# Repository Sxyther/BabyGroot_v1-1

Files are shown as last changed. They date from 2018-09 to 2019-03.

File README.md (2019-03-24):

# babygroot_v1-1
BabyGroot version 1.1 

---------------------------------------------------------------------------------------------------------------------
Software License: GPL v3

---------------------------------------------------------------------------------------------------------------------
Hardware License: CERN
Hardware released under an CERN Open Hardware Licence v1.2. See the LICENSE_HARDWARE file for more information.

---------------------------------------------------------------------------------------------------------------------
Documentation License: Creative Commons
Esta obra está bajo una Licencia Creative Commons Atribución-CompartirIgual 4.0 Internacional.

MakersGDL is a registered trademark, please do not use if you reproduce to sell PCBs.

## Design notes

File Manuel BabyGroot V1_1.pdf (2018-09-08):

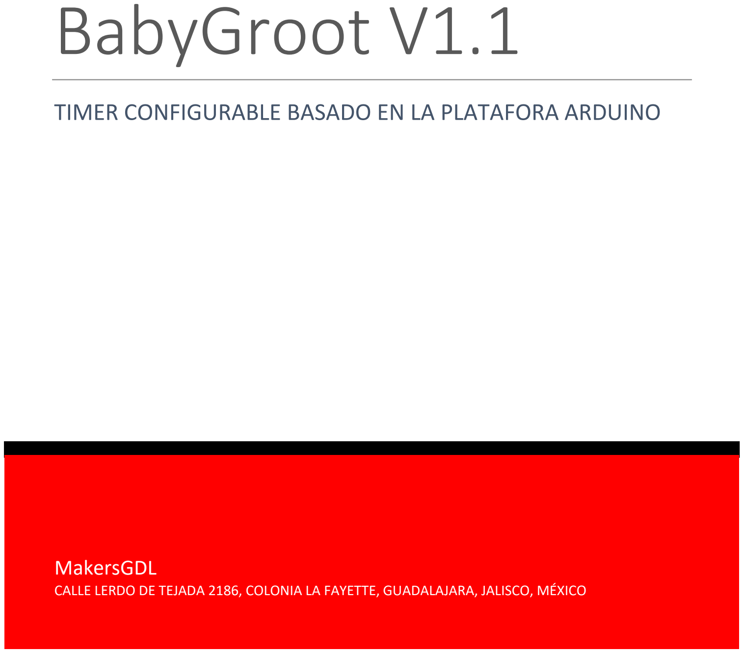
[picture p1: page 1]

[Escriba aquí] | [Escriba aquí] | [Escriba aquí]

## MakersGDL

CALLE LERDO DE TEJADA 2186, COLONIA LA FAYETTE, GUADALAJARA, JALISCO, MÉXICO

# BabyGroot V1.1

## TIMER CONFIGURABLE BASADO EN LA PLATAFORA ARDUINO

MakersGDL
www.makersgdl.com | 2

# Tabla de Contenido

### 1. INTRODUCCION A BABYGROOT V1.1

Dentro de la cultura MAKER la automatización juega un reto muy importante y desafiante. Así nace BabyGroot V1, por una necesidad de controlar valvular para el riego de un jardín a bajo costo.

### 2. DESCRIPCIÓN DE BABYGROOT V1.1

Esta guía se solo cubre BabyGroot V1.1, la tarjeta está diseñada para trabajar como un Arduino UNO vía un convertidor FTDI al puerto USB de la computadora.

Características | Detalles
Nombre | BabyGroot V1.1
Uso | Riego, invernadero, iluminación, bombas.
Canales PWM | 4
Entrada Análogos | 4
Entrada Digitales | 6
Protocolo de Comunicación | 1wire, I2C, SPI
Corriente de Entrada | 12v, 2A
Corriente de Salida | 12v
Indicador de Estatus | SI
Pantalla LCD | OPCIONAL, puede conectarse con I2C
Menú de Programación | NO, puede usarse botone de entrada
Programador en Tarjeta | NO, necesitas un TTL a USB
Software para programar | IDE Arduino
Conexión WIFI | OPCIONAL, pines disponibles
Conexión Bluetooth | OPCIONAL, pines disponibles

MakersGDL

### 3. INSTRUCCIONES DE ENSAMBLADO

Esta sección cubre el ensamblaje de la tarjeta controladora BabyGroot v1.1. Se acerca esta tarea como un ejercicio de aprendizaje, para desarrollar habilidades y autoconfianza. Este proyecto en sí es muy fácil y si sigues los pasos con cuidado, debes de terminar con un controlador funcionando completamente.

### 3.1. BabyGroot V1.1 / lista de componentes

El siguiente listado de componentes es para construir la tarjeta BabyGroot V1.1, la lista la puedes conseguir directamente con Mouser o en tu tienda de electrónica local.

Referencia | Descripción | Cantidad | Mouser P/N | Alterno P/N
D1 | 1N4004 diodo | 1
C1 | 0.1uF capacitor | 1
C2 - C3 | 22pF capacitor | 2
C4 | 4.7uF capacitor electrolítico | 1
C5 | 0.47uF capacitor electrolítico | 1
R1 - R2 | 4.7k ohm resistencia 1/8 watt | 2
R3 | 15k ohm resistencia 1/8 watt | 1
R4 - R9 | 470 ohm resistencia 1/8 watt | 6
LED1 – LED5 | 3mm led azul | 5
LED6 | 3mm led rojo | 1
OUT1-OUT5 | Borne doble | 5
PWRIN | Borne doble | 1
JP1, JP6 | 6 pines header hembra | 1
JP2, JP5 – JP8 | 3 pines header macho | 5
IC1 | Atmel 328p | 1
IC2 | ULN2003AN | 1
IC3 | 7805TV | 1
1 | Botón | 1
Q1 | Cristal 16mhz | 1
R1 | Reloj DS3231 | 1
U1 | DC-Jack | 1

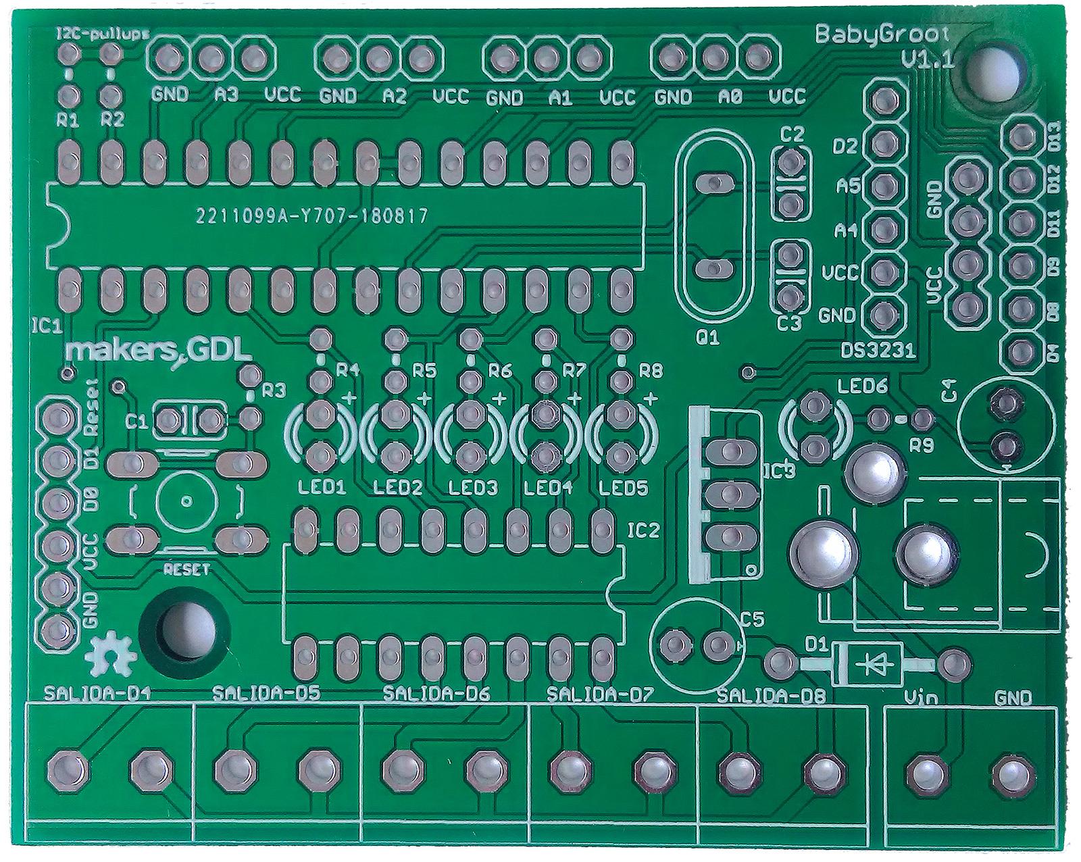
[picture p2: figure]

MakersGDL

### 3.2. Pasos para ensamblaje

La tarjeta BabyGroot V1.1 es un dispositivo muy simple de ensamblaje y de prueba.

### 3.2.1. Primero lo primero

Empezaremos en inspeccionar la PCB buscando que no tenga defectos como pistas cortadas. Las perforaciones en la PCB deben estar abiertas en ambos lados de la tarjeta.

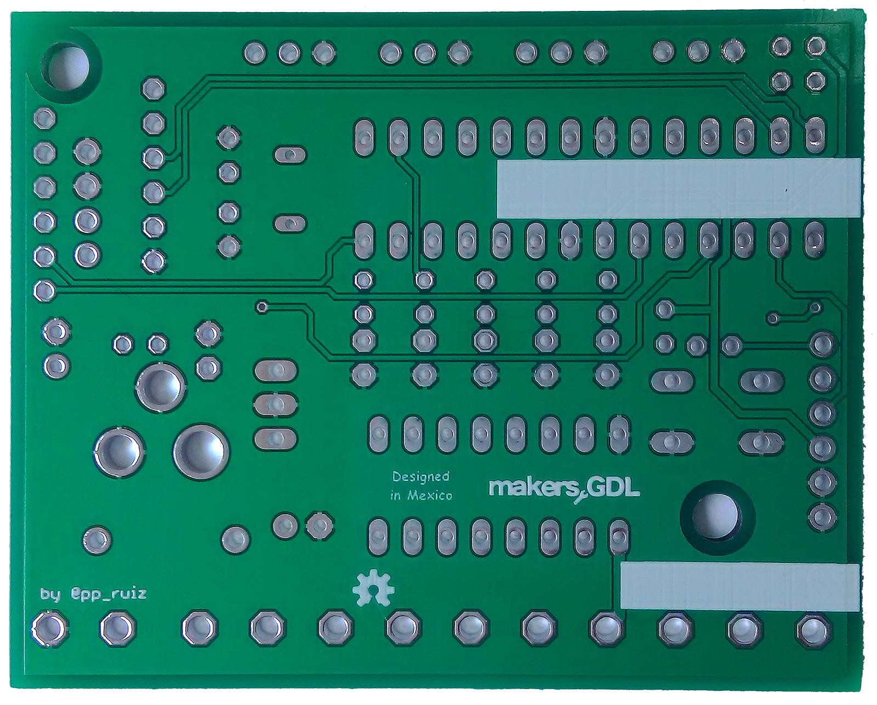
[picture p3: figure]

MakersGDL
www.makersgdl.com
5

MakersGDL

### 3.3. Guía de ensamble 3.3.1. Instalación de resistencias

Las resistencias no tienen una orientación específica y pueden instalarse en cualquier dirección. El VALOR si es importante y es indicado por las franjas de color.

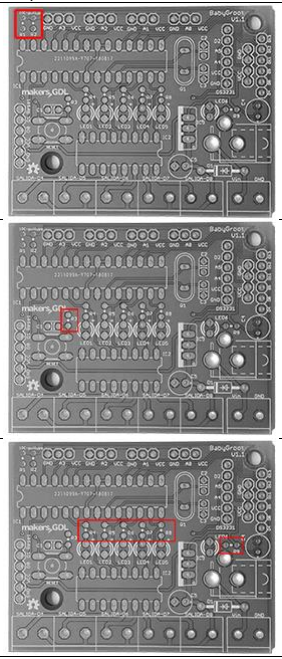
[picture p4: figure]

Paso | Instrucciones | BabyGroot V1.1
1 | Instalar resistencia 4.7k ohm (amarillo, morado, rojo) en las referencias R1 y R2. Soldar y cortar excesos.
2 | Instalar resistencia 15k ohm (café, verde, naranja) en las referencias R3. Soldar y cortar excesos.
3 | Instalar resistencia 470 ohm (amarillo, morado, café) en las referencias R4 a R9. Soldar y cortar excesos.

MakersGDL

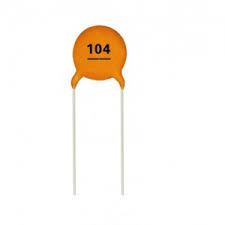
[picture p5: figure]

### 3.3.2. Instalación de capacitores y diodos

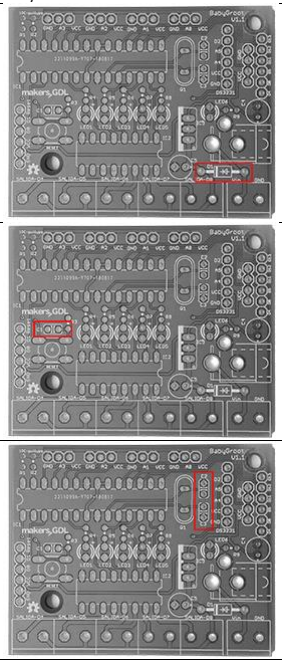
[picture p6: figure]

Paso | Instrucciones | BabyGroot V1.1
4 | Instalar diodo 1N4004 en la referencia D1. Soldar y cortar excesos.

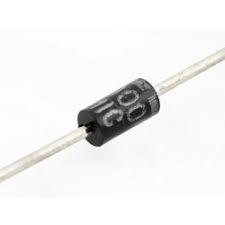
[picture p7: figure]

5 | Instalar Capacitor 0.1uF en la referencia C1. Soldar y corta excesos.
6 | Instalar Capacitor 22pF en la referencia C2, C3. Soldar y corta excesos.

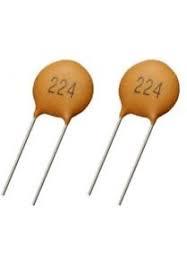
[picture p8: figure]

MakersGDL

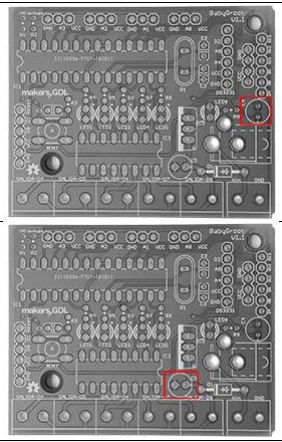
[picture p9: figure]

7 | Instalar Capacitor 4.7pF en la referencia C4. Soldar y corta excesos.

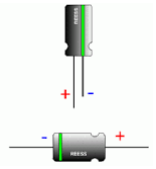
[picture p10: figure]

8 | Instalar Capacitor 0.47pF en la referencia C5. Soldar y corta excesos.

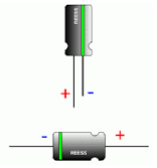
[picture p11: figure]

MakersGDL

### 3.3.3. Instalación de socket de ICs

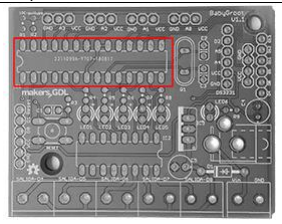
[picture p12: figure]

Paso | Instrucciones | BabyGroot V1.1
9 | Instalar socket de 28 pines en referencia IC1, colocar con la orientación de la muesca.

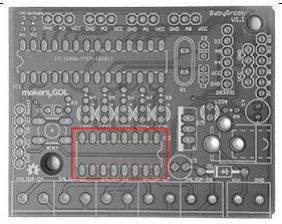
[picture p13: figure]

10 | Instalar socket de 16 pines en referencia IC2, colocar con la orientación de la muesca.

MakersGDL

### 3.3.4. Instalación de leds

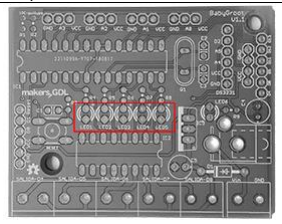
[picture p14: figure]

Paso | Instrucciones | BabyGroot V1.1
11 | Instalar LED Azul 3mm en referencia LED1 a LED5, pata más larga es positivo, soldar y cortar excesos. + -

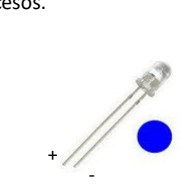
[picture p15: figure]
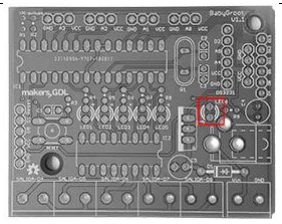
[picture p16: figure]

12 | Instalar LED Rojo 3mm en referencia LED6, pata más larga es positivo, soldar y cortar excesos.

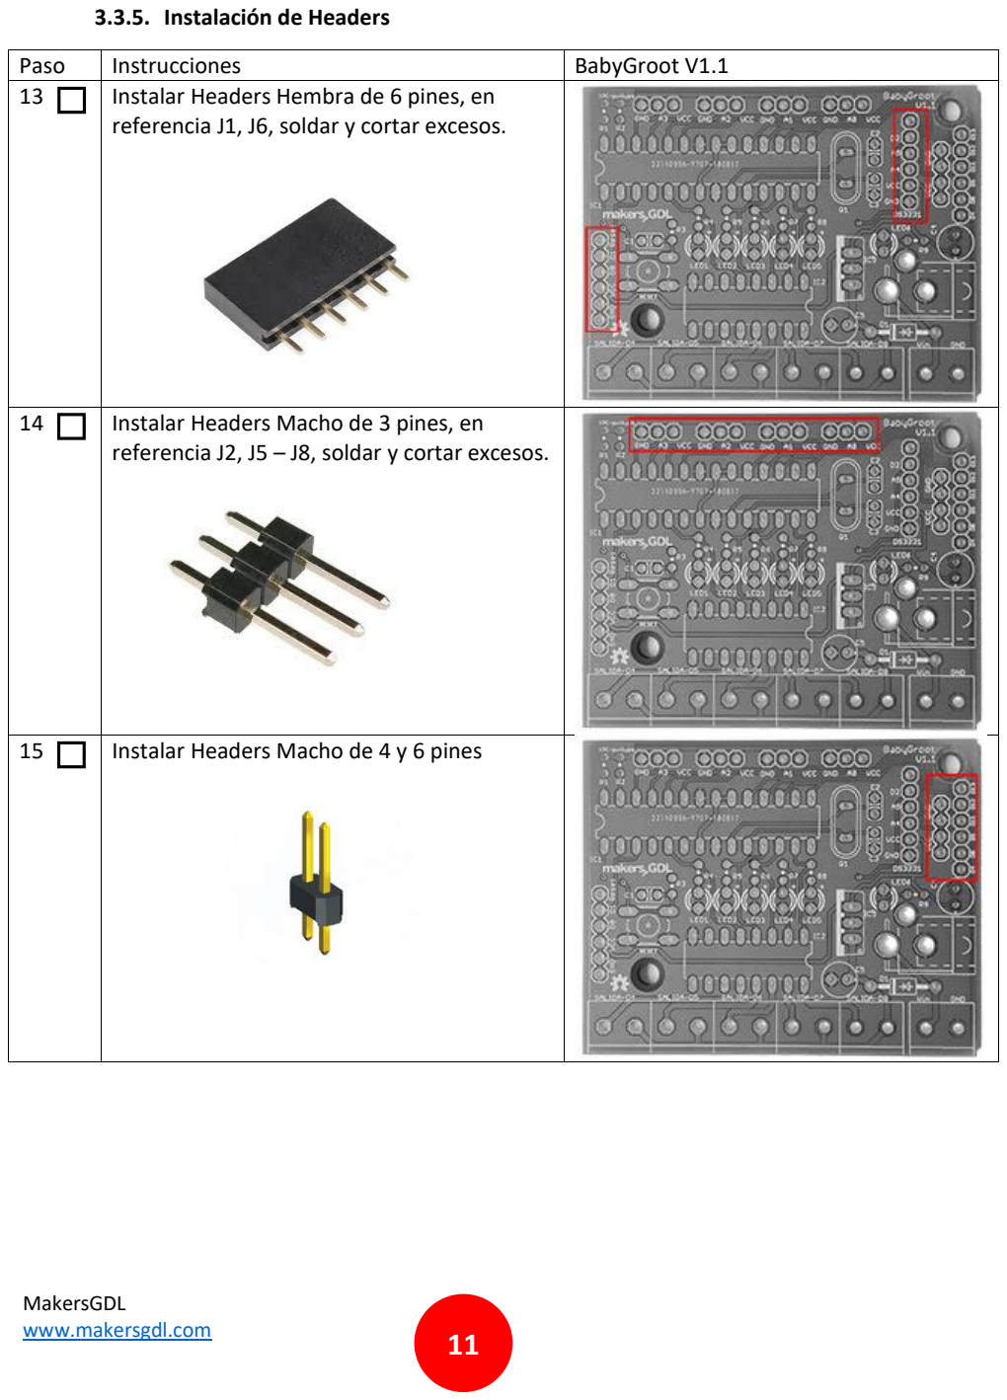
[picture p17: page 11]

MakersGDL

### 3.3.5. Instalación de Headers

Paso | Instrucciones | BabyGroot V1.1
13 | Instalar Headers Hembra de 6 pines, en referencia J1, J6, soldar y cortar excesos.
14 | Instalar Headers Macho de 3 pines, en referencia J2, J5 – J8, soldar y cortar excesos.
15 | Instalar Headers Macho de 4 y 6 pines

MakersGDL

### 3.3.6. Instalación de Misceláneos

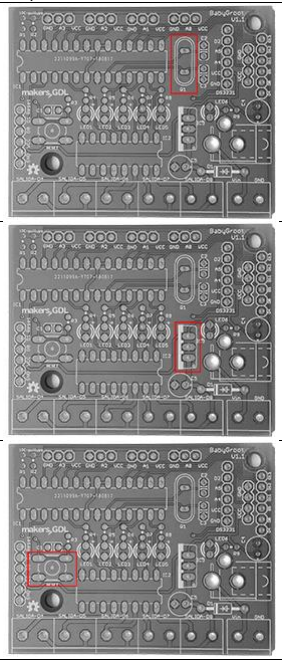
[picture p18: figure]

Paso | Instrucciones | BabyGroot V1.1
16 | Instalar Cristal 16mhz, en referencia Q1, soldar y cortar excesos.

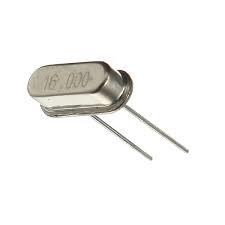
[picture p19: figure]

17 | Instalar 7805, en referencia IC3, soldar y cortar excesos.
18 | Instalar Botón de Reset, en referencia RESET, soldar y cortar excesos.

MakersGDL

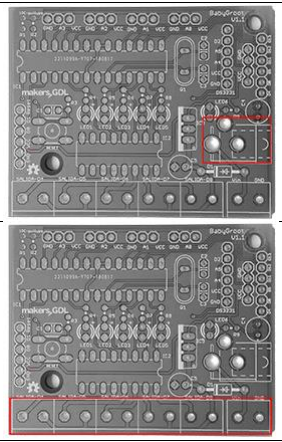
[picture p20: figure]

19 | Instalar DC JACK, en referencia U1, soldar y costra excesos.
20 | Instalar Bornes de Conexión, en referencia Salida D4, D5, D6, D7, D8 y Vin-GND, soldar y cortar excesos.

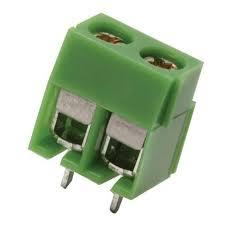
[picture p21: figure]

### 3.3.7. Test inicial

En este punto has ensamblado la tarjeta a excepción de la colocación de IC1, IC2, limpia la tarjeta con alcohol isopropílico o thinner de cualquier residuo de grasa o soldadura, revisa con una lupa que todas tus soldaduras estén correctas. Conecta la tarjeta a los 12volts, el led ROJO debe encender, vamos a validar la alimentación de IC1, IC2, IC3.

Con un multímetro medir el voltaje en el socket siguiendo los pines de la ilustración, si el voltaje no en +5 (4.8 – 5.2), desconecta el eliminador de la corriente.

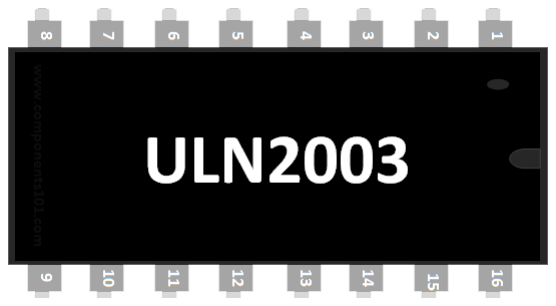
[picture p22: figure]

MakersGDL

### 3.3.8. Instalando ICs

Paso | Instrucciones | BabyGroot V1.1
21 | Instalar el ATMEL 328p en referencia IC1 dentro del socket, colocar con la orientación de la muesca.
22 | Instalar el ULN2003 pines en referencia IC2 dentro del socket, colocar con la orientación de la muesca.

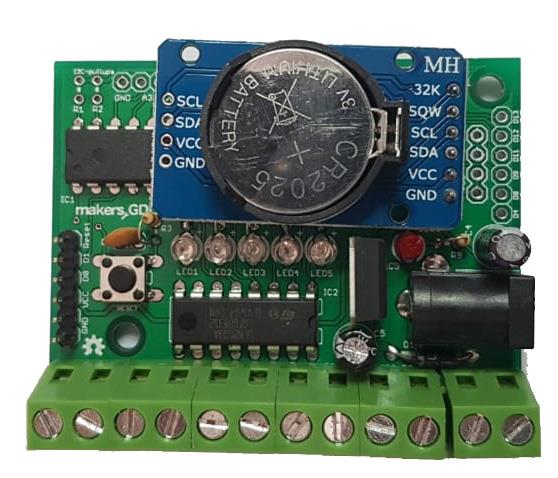
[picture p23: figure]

MakersGDL

### 3.3.9. Imagen de la Tarjeta Terminada

MakersGDL

### 4. PASOS FINALES

### 4.1. Programando el 328p

Para programar la tarjeta BabyGroot V1.1 necesitas un convertidos FTDI a USB

Conectar el cable Miniusb al FTDI y el USB al puerto de la computadora, abrir el IDE de Arduino utilizar la Tarjeta ARDUINO UNO y selecciona el puerto.

Si estas usan un 328P ya con el bootloader cargado, ya puedes empezar a programar, carga el código del 4.1.2 y haz la prueba.

Si no tienes cargado el bootloader sigue los siguientes pasos:

### 4.1.1. Librerías

Las librerías que debes usar por default son:

- 1 wire
- RTClib
4.1.2. Código de ejemplo para validar el encendido de los leds de estatus.

int delayTime = 1000;
void setup()
{
pinMode(3, OUTPUT);
pinMode(5, OUTPUT);
pinMode(6, OUTPUT);
pinMode(7, OUTPUT);
pinMode(10, OUTPUT);
}
void loop()
{
digitalWrite(3, HIGH); delay(delayTime); digitalWrite(3, LOW); delay(delayTime); digitalWrite(5, HIGH); delay(delayTime); digitalWrite(5, LOW); delay(delayTime); digitalWrite(6, HIGH); delay(delayTime); digitalWrite(6, LOW); delay(delayTime); digitalWrite(7, HIGH); delay(delayTime); digitalWrite(7, LOW); delay(delayTime); digitalWrite(10, HIGH); delay(delayTime); digitalWrite(10, LOW); delay(delayTime); }

MakersGDL

### 5. CONECTANDO LAS VALVULAS Y SENSORES

5.1. Tipos de válvulas

Existen varios tipos de válvulas (solenoides) para flujo de agua, la más común es la plástica

Esta válvula es la más común en los entusiastas de Arduino, sus conexiones de ½ pulgada, sor lo que si utilizarás una salida normal de llave deberás fabricar un adaptador

También existen las de bronce que son mucho más duraderas en el tiempo y cuentan con diversos diámetros para ser conectadas, su valor es de 3x de las pláticas.

Esta son las mejores bombas para riego, pueden permanecer bajo tierra a altas humedades, solo que no todas son a 12v, la mayoría son a 24v o 28v.

Por último, esta válvula de la marca ORBIT es para exterior fabricada en plástico con solenoide interno y funciona a 9v y 12v.

MakersGDL

### 5.2. Tipo de sensores

Primero hablaremos de los sensores análogos que nos ayudarán a obtener mediciones del suelo, nutrientes, si llueve o no, radiación solar, etc.

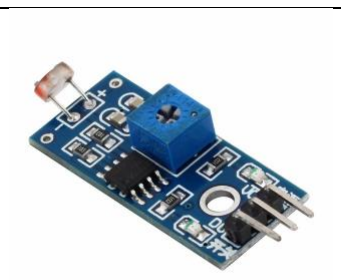
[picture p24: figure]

Sensor de Humedad Suelo | Sensor de Lluvia | Sensor de Luz | Sensor Radiación Solar

Sensores Digitales

Sensor Temp / Hum
Ambiente

Sensor Temp / Presión Sensor Infrarrojo de Temp

Sensor Temp Líquidos

MakersGDL

### 6. TESTEO FINAL

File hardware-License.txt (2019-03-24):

CERN Open Hardware Licence v1.2

Preamble

Through this CERN Open Hardware Licence ("CERN OHL") version 1.2, CERN
wishes to provide a tool to foster collaboration and sharing among
hardware designers.  The CERN OHL is copyright CERN. Anyone is welcome
to use the CERN OHL, in unmodified form only, for the distribution of
their own Open Hardware designs. Any other right is reserved. Release
of hardware designs under the CERN OHL does not constitute an
endorsement of the licensor or its designs nor does it imply any
involvement by CERN in the development of such designs.

1. Definitions

In this Licence, the following terms have the following meanings:

“Licence” means this CERN OHL.

“Documentation” means schematic diagrams, designs, circuit or circuit
board layouts, mechanical drawings, flow charts and descriptive text,
and other explanatory material that is explicitly stated as being made
available under the conditions of this Licence. The Documentation may
be in any medium, including but not limited to computer files and
representations on paper, film, or any other media.

“Documentation Location” means a location where the Licensor has
placed Documentation, and which he believes will be publicly
accessible for at least three years from the first communication to
the public or distribution of Documentation.

“Product” means either an entire, or any part of a, device built using
the Documentation or the modified Documentation.

“Licensee” means any natural or legal person exercising rights under
this Licence.

“Licensor” means any natural or legal person that creates or modifies
Documentation and subsequently communicates to the public and/ or
distributes the resulting Documentation under the terms and conditions
of this Licence.

A Licensee may at the same time be a Licensor, and vice versa.

Use of the masculine gender includes the feminine and neuter genders
and is employed solely to facilitate reading.

2. Applicability

2.1. This Licence governs the use, copying, modification,
communication to the public and distribution of the Documentation, and
the manufacture and distribution of Products. By exercising any right
granted under this Licence, the Licensee irrevocably accepts these
terms and conditions.

2.2. This Licence is granted by the Licensor directly to the Licensee,
and shall apply worldwide and without limitation in time. The Licensee
may assign his licence rights or grant sub-licences.

2.3. This Licence does not extend to software, firmware, or code
loaded into programmable devices which may be used in conjunction with
the Documentation, the modified Documentation or with Products, unless
such software, firmware, or code is explicitly expressed to be subject
to this Licence. The use of such software, firmware, or code is
otherwise subject to the applicable licence terms and conditions.

3. Copying, modification, communication to the public and distribution
of the Documentation

3.1. The Licensee shall keep intact all copyright and trademarks
notices, all notices referring to Documentation Location, and all
notices that refer to this Licence and to the disclaimer of warranties
that are included in the Documentation. He shall include a copy
thereof in every copy of the Documentation or, as the case may be,
modified Documentation, that he communicates to the public or
distributes.

3.2. The Licensee may copy, communicate to the public and distribute
verbatim copies of the Documentation, in any medium, subject to the
requirements specified in section 3.1.

3.3. The Licensee may modify the Documentation or any portion thereof
provided that upon modification of the Documentation, the Licensee
shall make the modified Documentation available from a Documentation
Location such that it can be easily located by an original Licensor
once the Licensee communicates to the public or distributes the
modified Documentation under section 3.4, and, where required by
section 4.1, by a recipient of a Product. However, the Licensor shall
not assert his rights under the foregoing proviso unless or until a
Product is distributed.

3.4. The Licensee may communicate to the public and distribute the
modified Documentation (thereby in addition to being a Licensee also
becoming a Licensor), always provided that he shall:

a) comply with section 3.1;

b) cause the modified Documentation to carry prominent notices stating
that the Licensee has modified the Documentation, with the date and
description of the modifications;

c) cause the modified Documentation to carry a new Documentation
Location notice if the original Documentation provided for one;

d) make available the modified Documentation at the same level of
abstraction as that of the Documentation, in the preferred format for
making modifications to it (e.g. the native format of the CAD tool as
applicable), and in the event that format is proprietary, in a format
viewable with a tool licensed under an OSI-approved license if the
proprietary tool can create it; and

e) license the modified Documentation under the terms and conditions
of this Licence or, where applicable, a later version of this Licence
as may be issued by CERN.

3.5. The Licence includes a non-exclusive licence to those patents or
registered designs that are held by, under the control of, or
sub-licensable by the Licensor, to the extent necessary to make use of
the rights granted under this Licence. The scope of this section 3.5
shall be strictly limited to the parts of the Documentation or
modified Documentation created by the Licensor.

4. Manufacture and distribution of Products

4.1. The Licensee may manufacture or distribute Products always
provided that, where such manufacture or distribution requires a
licence under this Licence the Licensee provides to each recipient of
such Products an easy means of accessing a copy of the Documentation
or modified Documentation, as applicable, as set out in section 3.

4.2. The Licensee is invited to inform any Licensor who has indicated
his wish to receive this information about the type, quantity and
dates of production of Products the Licensee has (had) manufactured

5. Warranty and liability

5.1. DISCLAIMER – The Documentation and any modified Documentation are
provided "as is" and any express or implied warranties, including, but
not limited to, implied warranties of merchantability, of satisfactory
quality, non-infringement of third party rights, and fitness for a
particular purpose or use are disclaimed in respect of the
Documentation, the modified Documentation or any Product. The Licensor
makes no representation that the Documentation, modified
Documentation, or any Product, does or will not infringe any patent,
copyright, trade secret or other proprietary right. The entire risk as
to the use, quality, and performance of a Product shall be with the
Licensee and not the Licensor. This disclaimer of warranty is an
essential part of this Licence and a condition for the grant of any
rights granted under this Licence. The Licensee warrants that it does
not act in a consumer capacity.

5.2. LIMITATION OF LIABILITY – The Licensor shall have no liability
for direct, indirect, special, incidental, consequential, exemplary,
punitive or other damages of any character including, without
limitation, procurement of substitute goods or services, loss of use,
data or profits, or business interruption, however caused and on any
theory of contract, warranty, tort (including negligence), product
liability or otherwise, arising in any way in relation to the
Documentation, modified Documentation and/or the use, manufacture or
distribution of a Product, even if advised of the possibility of such
damages, and the Licensee shall hold the Licensor(s) free and harmless
from any liability, costs, damages, fees and expenses, including
claims by third parties, in relation to such use.

6. General

6.1. Except for the rights explicitly granted hereunder, this Licence
does not imply or represent any transfer or assignment of intellectual
property rights to the Licensee.

6.2. The Licensee shall not use or make reference to any of the names
(including acronyms and abbreviations), images, or logos under which
the Licensor is known, save in so far as required to comply with
section 3. Any such permitted use or reference shall be factual and
shall in no event suggest any kind of endorsement by the Licensor or
its personnel of the modified Documentation or any Product, or any
kind of implication by the Licensor or its personnel in the
preparation of the modified Documentation or Product.

6.3. CERN may publish updated versions of this Licence which retain
the same general provisions as this version, but differ in detail so
far this is required and reasonable. New versions will be published
with a unique version number.

6.4. This Licence shall terminate with immediate effect, upon written
notice and without involvement of a court if the Licensee fails to
comply with any of its terms and conditions, or if the Licensee
initiates legal action against Licensor in relation to this
Licence. Section 5 shall continue to apply.

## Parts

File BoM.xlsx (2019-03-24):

Descripcion | Cantidad | Numero de parte | Proveedor | Link
Vreg 5v | 1 | L7805CV | AG | http://www.agspecinfo.com/pdfs/L/L7805CV.PDF
Diodo | 1 | 1N4004 | AG | http://www.agspecinfo.com/pdfs/1/1N4004.PDF
Led Azul | 5 | LED-B3D-AC-R30 | AG | http://www.agspecinfo.com/pdfs/L/LEDY3DYT.PDF
Led Rojo | 1 | LED-R3D-AD-R30 | AG | http://www.agspecinfo.com/pdfs/L/LEDY3DYT.PDF
Push button | 1 | PUSH-1 | AG | http://www.agspecinfo.com/pdfs/P/PUSH-1.PDF
Bornera | 6 | TRTG-02 | AG | http://www.agspecinfo.com/pdfs/T/TRTG02.PDF
Capacitor 22 pf | 2 | CC-22/1000V-WELSON | Mouser | https://www.mouser.mx/ProductDetail/Vishay-BC-Components/K220J15C0GF5TL2
capacitor 0.47uF | 1 | CE-.47/100V-TEAPO | AG | http://www.agspecinfo.com/pdfs/S/SH.PDF
capacitor 4.7uF | 1 | CE-4.7/35V-TEAPO | AG | http://www.agspecinfo.com/pdfs/T/TEAPO_SE.PDF
capacitor 100nF | 1 | CC-.1/50V-WELSON | AG | http://www.agspecinfo.com/pdfs/C/CERAMICO.PDF
Resistencia 470 | 6 | RC-470E/1/8 | AG
Resistencia 15k | 1 | RC-15K/1/8 | AG
Power Jack | 1 | DC-005-2.1R | Mouser | DC-005-2.1R (https://www.mouser.mx/ProductDetail/CUI/PJ-202B)
Cristal | 1 | LFXTAL003240Bulk | Mouser | https://www.mouser.mx/ProductDetail/IQD/LFXTAL003240Bulk
MCU | 1 | ATMEGA328-PU | Mouser | https://www.mouser.mx/ProductDetail/Microchip-Technology-Atmel/ATMEGA328-PU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
Darlington Array |  | ULN2003A | Mouser | https://www.mouser.mx/ProductDetail/STMicroelectronics/ULN2003A?qs=sGAEpiMZZMvAvBNgSS9LqkBZ7AC8MBp%2F

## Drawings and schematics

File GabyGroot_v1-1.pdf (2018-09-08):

VCC 7 | AGND 22 | AREF 21

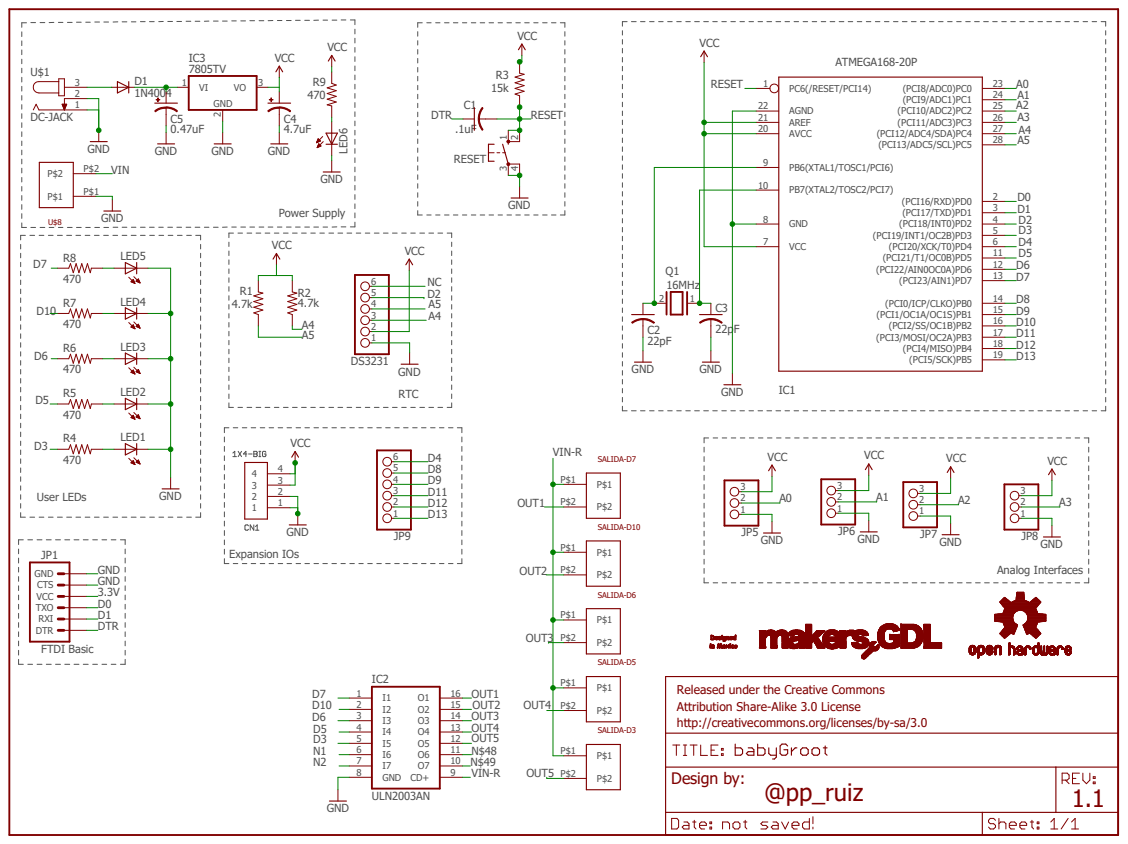
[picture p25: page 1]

GND
SALIDA-D7 SALIDA-D10 SALIDA-D6 SALIDA-D5

Released under the Creative Commons
Attribution Share-Alike 3.0 License
http://creativecommons.org/licenses/by-sa/3.0

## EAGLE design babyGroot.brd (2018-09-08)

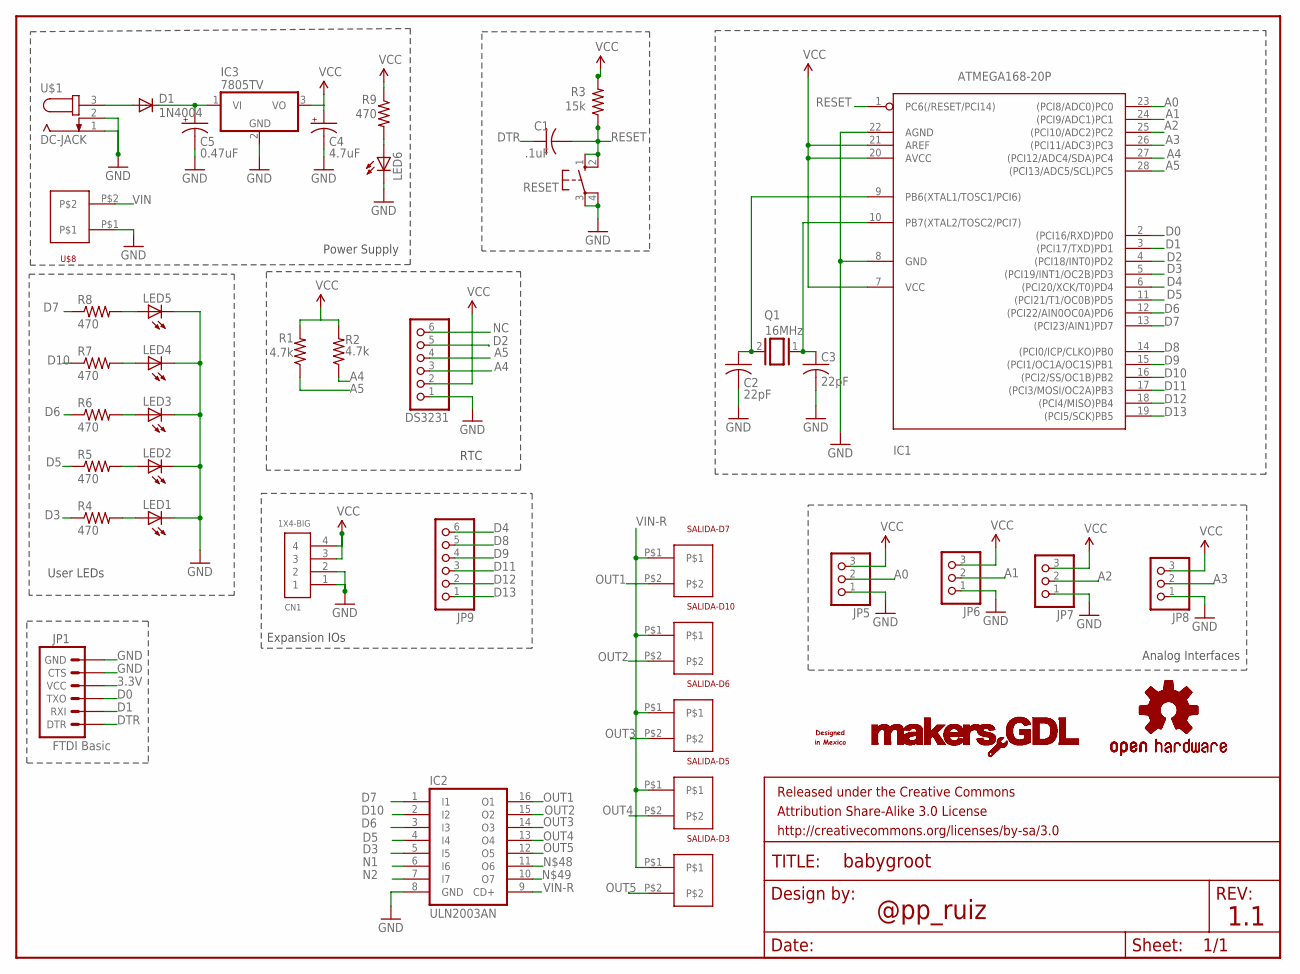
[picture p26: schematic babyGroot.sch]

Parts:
C1: .1uF; C025-024X044
C2, C3: 22pF; C025-024X044
C4: 4.7uF; E2,5-6E
C5: 0.47uF; E2,5-6E
CN1: 1X4-BIG; 1X04-BIG
D1: 1N4004; DO41-10
DS3231: PINHD-1X6; 1X06
FRAME1: FRAME-LETTER; CREATIVE_COMMONS
IC1: ATMEGA168-20P; DIL28-3
IC2: ULN2003AN; DIL16
IC3: 7805TV; TO220V
JP1: FTDI Basic; 1X06
JP5, JP6, JP7, JP8: PINHD-1X3; 1X03
JP9: PINHD-1X6; 1X06
LED1, LED2, LED3, LED4, LED5, LED6: LED3MM
Q1: 16MHz; QS
R1, R2: 4.7k; 0204V
R3: 15k; 0204V
R4, R5, R6, R7, R8, R9: 470; 0204V
RESET: 10-XX; B3F-10XX
SALIDA-D3, SALIDA-D5, SALIDA-D6, SALIDA-D7, SALIDA-D10: 2POSHEADER-0.5MM; 2PIN-0.5MM
U$1: DC-JACK; SPC4078
U$2, U$4: MAKERSGDLLOGO-SMALL; MAKERSGGL-SMALL
U$3, U$5: OSHW-LOGOS; OSHW-LOGO-S
U$6: DESIGNEDMEXICO
U$8: 2POSHEADER-0.5MM; 2PIN-0.5MM

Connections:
3.3V: C4.+, CN1.3, CN1.4, DS3231.2, IC1.7 (VCC), IC1.20 (AVCC), IC1.21 (AREF), IC3.3 (VO), JP1.4 (VCC), JP5.3, JP6.3, JP7.3, JP8.3, R1.2, R2.2, R3.2, R9.1
A0: IC1.23 ((PCI8/ADC0)PC0), JP5.2
A1: IC1.24 ((PCI9/ADC1)PC1), JP6.2
A2: IC1.25 ((PCI10/ADC2)PC2), JP7.2
A3: IC1.26 ((PCI11/ADC3)PC3), JP8.2
A4: DS3231.3, IC1.27 ((PCI12/ADC4/SDA)PC4), R2.1
A5: DS3231.4, IC1.28 ((PCI13/ADC5/SCL)PC5), R1.1
D0: IC1.2 ((PCI16/RXD)PD0), JP1.3 (TXO)
D1: IC1.3 ((PCI17/TXD)PD1), JP1.2 (RXI)
D2: DS3231.5, IC1.4 ((PCI18/INT0)PD2)
D3: IC1.5 ((PCI19/INT1/OC2B)PD3), IC2.5 (I5), R4.1
D4: IC1.6 ((PCI20/XCK/T0)PD4), JP9.6
D5: IC1.11 ((PCI21/T1/OC0B)PD5), IC2.4 (I4), R5.1
D6: IC1.12 ((PCI22/AIN0OC0A)PD6), IC2.3 (I3), R6.1
D7: IC1.13 ((PCI23/AIN1)PD7), IC2.1 (I1), R8.1
D8: IC1.14 ((PCI0/ICP/CLKO)PB0), JP9.5
D9: IC1.15 ((PCI1/OC1A/OC1S)PB1), JP9.4
D10: IC1.16 ((PCI2/SS/OC1B)PB2), IC2.2 (I2), R7.1
D11: IC1.17 ((PCI3/MOSI/OC2A)PB3), JP9.3
D12: IC1.18 ((PCI4/MISO)PB4), JP9.2
D13: IC1.19 ((PCI5/SCK)PB5), JP9.1
DTR: C1.1, JP1.1 (DTR)
GND: C2.2, C3.2, C4.-, C5.-, CN1.1, CN1.2, DS3231.1, IC1.8 (GND), IC1.22 (AGND), IC2.8 (GND), IC3.2 (GND), JP1.5 (CTS), JP1.6 (GND), JP5.1, JP6.1, JP7.1, JP8.1, LED1.K (C), LED2.K (C), LED3.K (C), LED4.K (C), LED5.K (C), LED6.K (C), RESET.3, RESET.4 (P1), U$1.1, U$1.2, U$8.P$1
N1: IC2.6 (I6)
N2: IC2.7 (I7)
unnamed: C2.1, IC1.9 (PB6(XTAL1/TOSC1/PCI6)), Q1.2
unnamed: C3.1, IC1.10 (PB7(XTAL2/TOSC2/PCI7)), Q1.1
unnamed: LED6.A, R9.2
unnamed: LED5.A, R8.2
unnamed: LED4.A, R7.2
unnamed: LED3.A, R6.2
unnamed: LED2.A, R5.2
unnamed: LED1.A, R4.2
NC: DS3231.6
OUT1: IC2.16 (O1), SALIDA-D7.P$2
OUT2: IC2.15 (O2), SALIDA-D10.P$2
OUT3: IC2.14 (O3), SALIDA-D6.P$2
OUT4: IC2.13 (O4), SALIDA-D5.P$2
OUT5: IC2.12 (O5), SALIDA-D3.P$2
RESET: C1.2, IC1.1 (PC6(/RESET/PCI14)), R3.1, RESET.1 (S), RESET.2 (S1)
VIN: D1.A, U$1.3, U$8.P$2
VIN-R: C5.+, D1.C, IC2.9 (CD+), IC3.1 (VI), SALIDA-D3.P$1, SALIDA-D5.P$1, SALIDA-D6.P$1, SALIDA-D7.P$1, SALIDA-D10.P$1

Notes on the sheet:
User LEDs
@pp_ruiz
1.1
Power Supply
RTC
Analog Interfaces
Expansion IOs

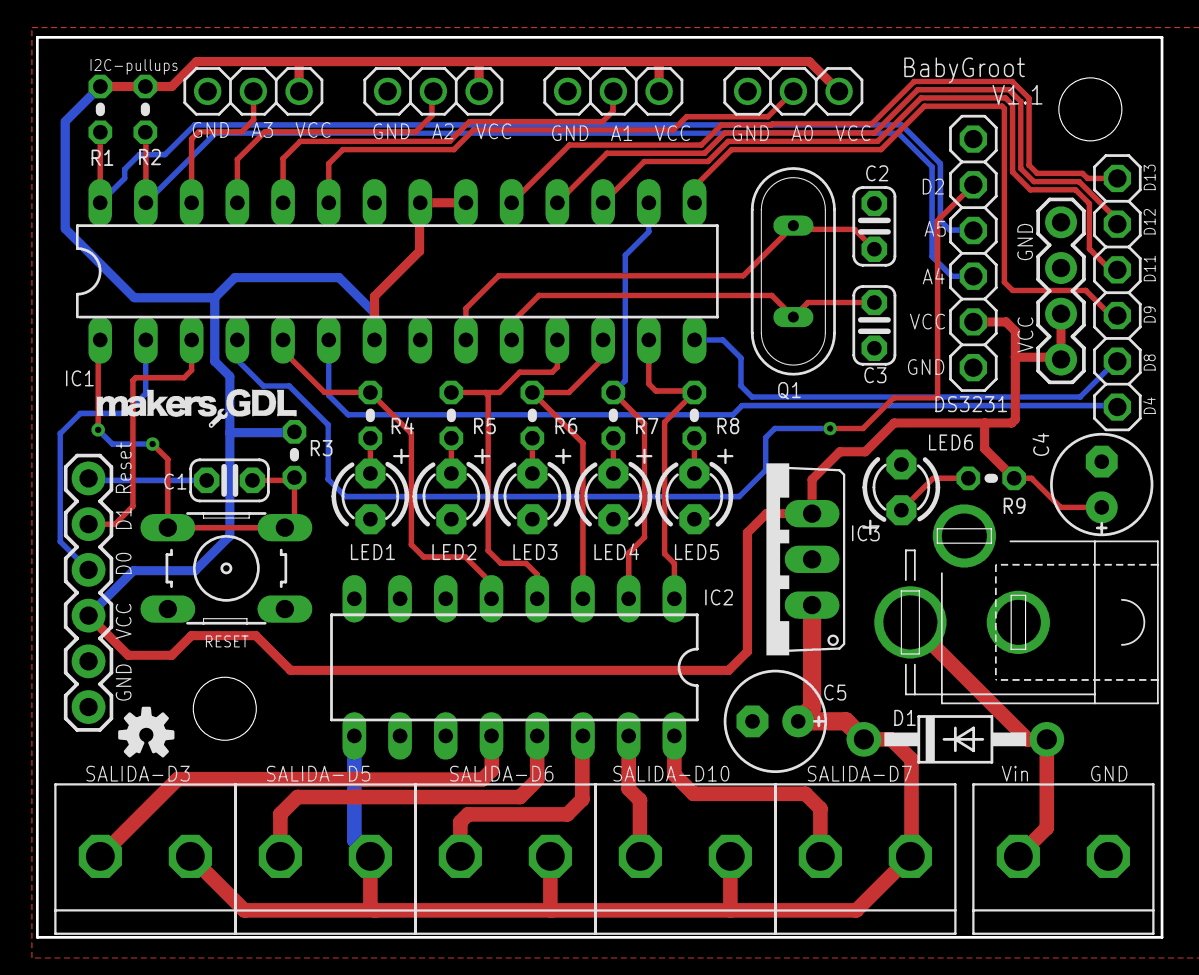
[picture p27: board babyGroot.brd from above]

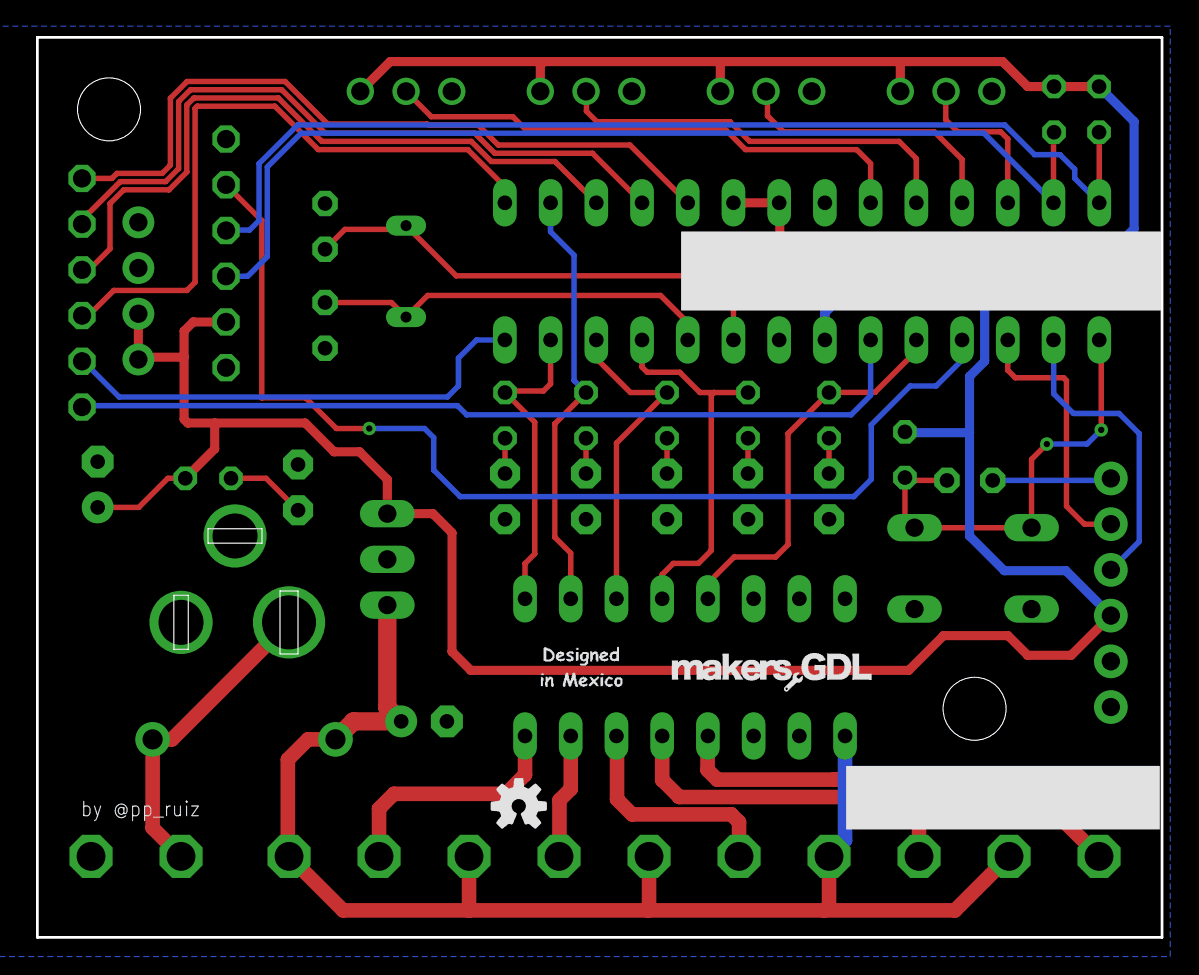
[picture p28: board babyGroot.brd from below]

Board: 2 copper layers, 62.5 x 50.0 mm, 47 parts (3 on the bottom side), 39 nets.

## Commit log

2018-09-08 BabyGroot v1.1 Schematic
2018-09-08 Design Files
    [babyGroot.brd, babyGroot.sch]
2018-09-08 Manual de BabyGroot

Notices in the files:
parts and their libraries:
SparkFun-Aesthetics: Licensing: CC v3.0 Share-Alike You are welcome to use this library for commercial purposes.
